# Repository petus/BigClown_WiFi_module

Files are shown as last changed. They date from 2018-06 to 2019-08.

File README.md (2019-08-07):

# BigClown WiFi module v1.0</br>
WiFi module for BigClown platform</br>
</br>
This WiFi module is developed for BigClown IoT platform. The WiFi module can be ESP07 or ESP12E (ESP8266 IC).</br>
</br>
How to use WiFi module for BigClown </br>
(czech language) - https://chiptron.cz/articles.php?article_id=182</br>
(english) - https://time4ee.com/articles.php?article_id=113</br>
</br>
The Wi-Fi module is supported by BigClown SDK</br>
https://github.com/bigclownlabs/bcf-sdk/blob/master/bcl/src/bc_esp8266.c</br>
Example with Wi-Fi module</br>
https://github.com/bigclownprojects/bcf-wifi-cryptoclock</br>

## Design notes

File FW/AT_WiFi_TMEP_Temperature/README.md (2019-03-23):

WiFi module with built-in temperature TMP112</br>
Temperature TMP112 sensor (I2C0) is built-in BigClown Core module</br>
and the sensor sends temperature to BigClown and then the BigClown </br>
sends the temperature to tmep.eu or tmep.cz by WiFi conection (WiFi module)</br>
CH_EN pin of ESP8266 module is connected GPIO_P8</br>
Reset pin of ESP8266 module is connected to GPIO_P6</br>
Created by Petus (2019)</br>
(czech)</br>
WiFi module https://chiptron.cz/articles.php?article_id=182</br>
(english)</br>
WiFi module https://time4ee.com/articles.php?article_id=113</br>
</br>
Fill in the</br>
static char host[]="HOSTNAME.tmep.eu";</br>
static char SSID[]="\"SSID\",";</br>
static char PASSWORD[]="\"PASSWORD\"";</br>
</br>
FW uses the TMP112 sensor on Core module

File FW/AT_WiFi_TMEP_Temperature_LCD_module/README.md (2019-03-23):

WiFi module with built-in TMP112 and LCD module</br>
Temperature TMP112 sensor (I2C0) is buil-in Core module</br>
and the sensor sends temperature to BigClown and then the BigClown </br>
sends the temperature to tmep.eu or tmep.cz by WiFi conection (WiFi module).</br>
The temperature is also shown on LCD</br>
CH_EN pin of ESP8266 module is connected GPIO_P8</br>
Reset pin of ESP8266 module is connected to GPIO_P6</br>
Created by Petus (2019)</br>
(czech)</br>
WiFi module https://chiptron.cz/articles.php?article_id=182</br>
(english)</br>
WiFi module https://time4ee.com/articles.php?article_id=113</br>
</br>
Fill in the</br>
static char host[]="HOSTNAME.tmep.eu";</br>
static char SSID[]=""SSID",";</br>
static char PASSWORD[]=""PASSWORD"";</br>
</br>
FW uses the TMP112 sensor on Core module</br>
</br>
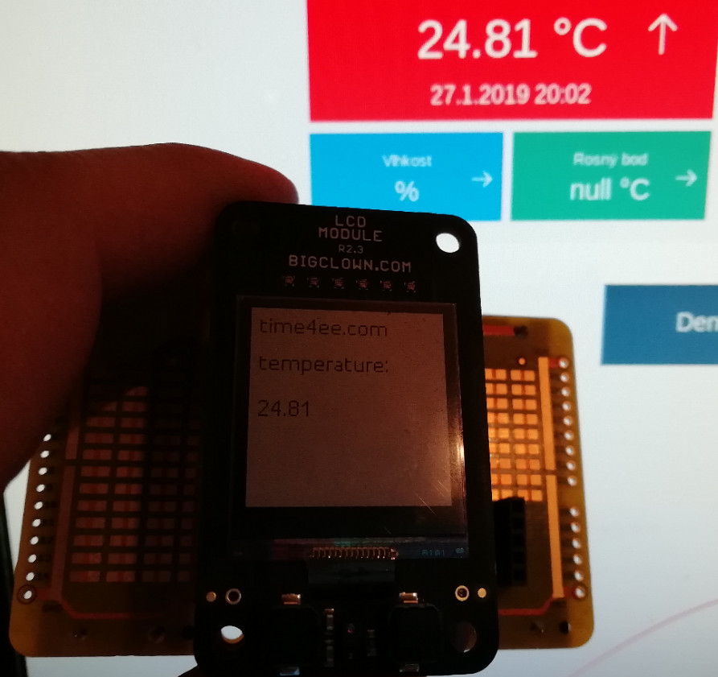
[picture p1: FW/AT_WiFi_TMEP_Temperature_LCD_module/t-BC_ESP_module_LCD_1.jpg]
BigClown and WiFi module


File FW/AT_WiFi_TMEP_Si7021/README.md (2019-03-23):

WiFi module and Sensor adapter - Si7021 example code (temperature)</br>
This example code demonstrates the settings and communication with temperature and humidity sensor Si7021 (0x40) and popular IoT platform called BigClown - https://www.bigclown.com/ .</br>
</br>
Created by Petus (2019)</br>
(czech) www.chiptron.cz - </br>
WiFi module https://chiptron.cz/articles.php?article_id=182</br>
Sensor adapter https://chiptron.cz/articles.php?article_id=194</br>
(english) www.time4ee.com - </br>
WiFi module https://time4ee.com/articles.php?article_id=113</br>
Sensor adapter https://time4ee.com/articles.php?article_id=119</br>

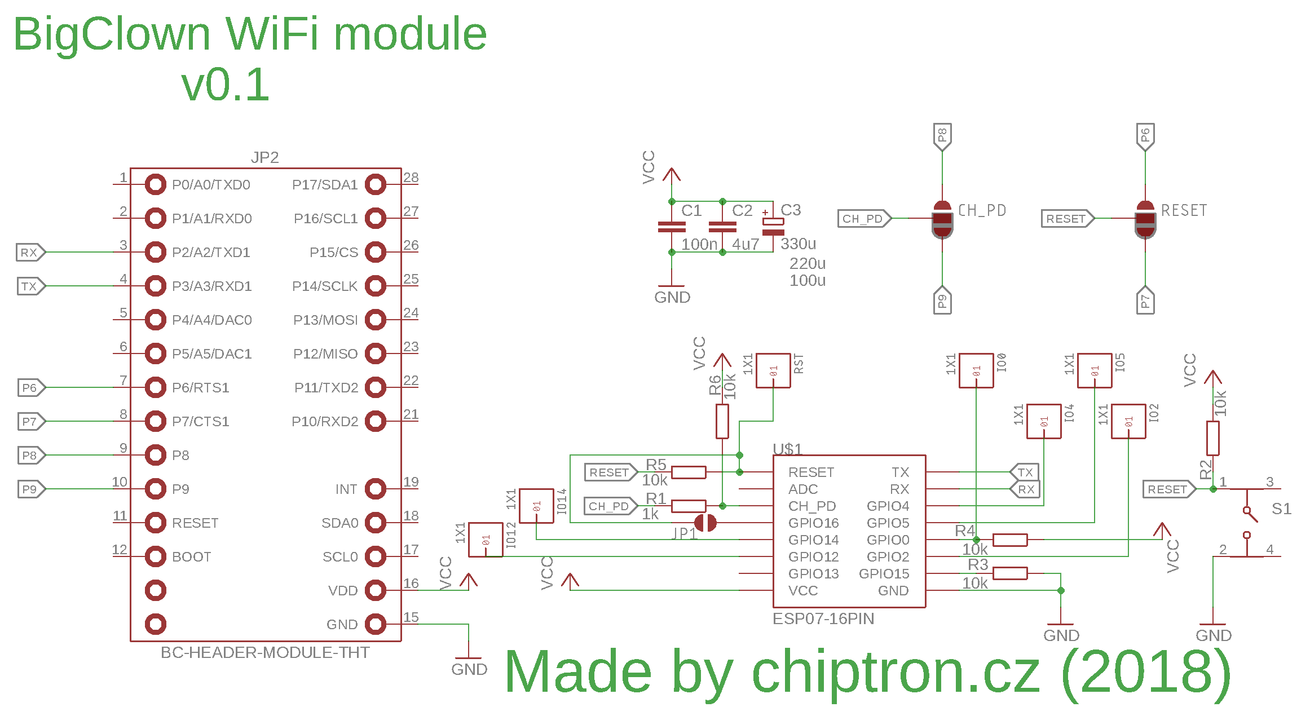
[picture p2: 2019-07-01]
BigClown_WiFi_module_sch.png

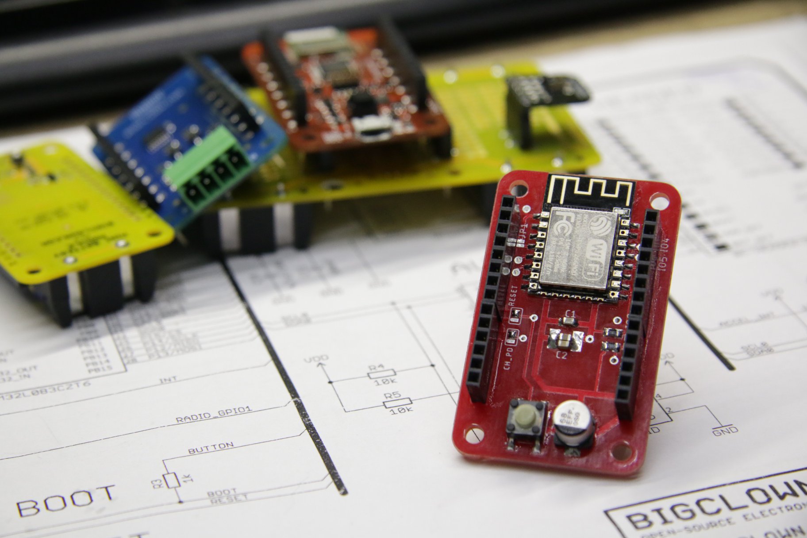
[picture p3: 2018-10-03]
Pictures/BigClown_WiFi_module_2_v1.0.jpg

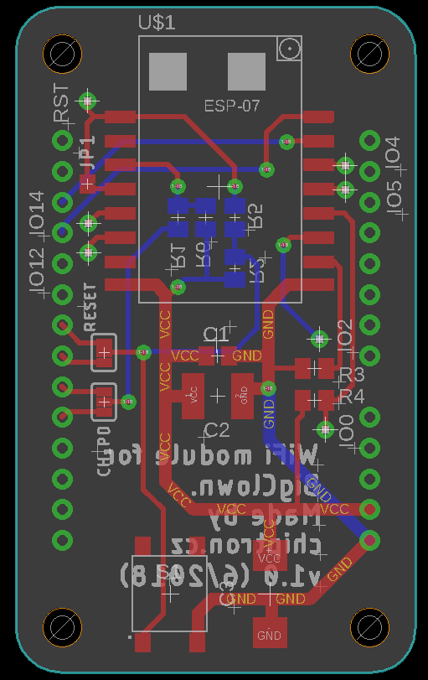
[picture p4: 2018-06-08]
BigClown_WiFi_module_brd.png

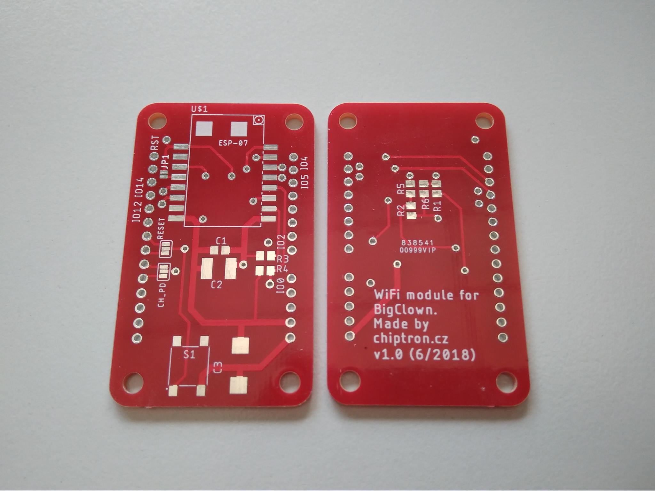
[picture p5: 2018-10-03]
Pictures/BigClown_WiFi_module_3_v1.0.jpg

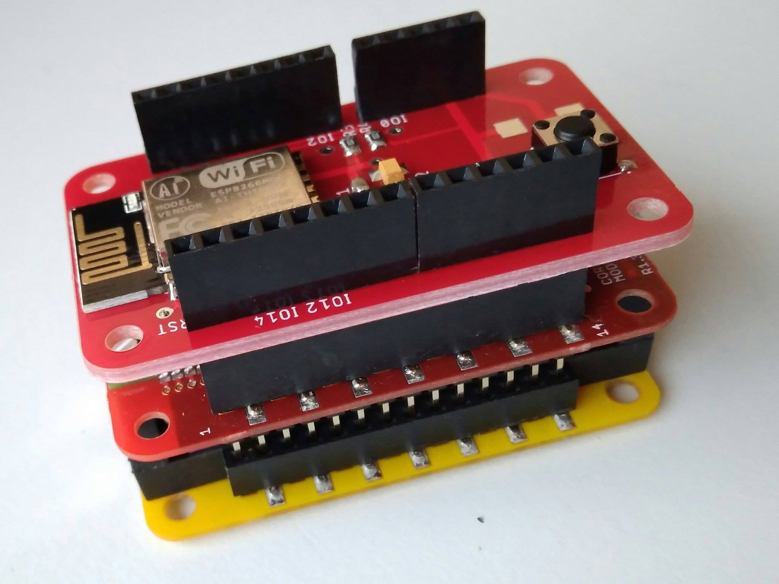
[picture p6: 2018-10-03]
Pictures/BigClown_WiFi_module_1_v1.0.jpg

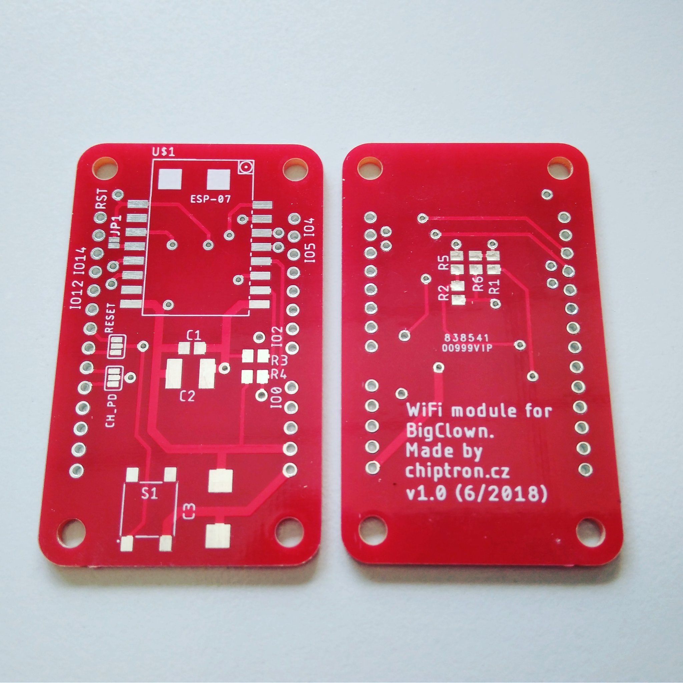
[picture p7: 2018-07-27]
BigClown_WiFi_module.jpeg

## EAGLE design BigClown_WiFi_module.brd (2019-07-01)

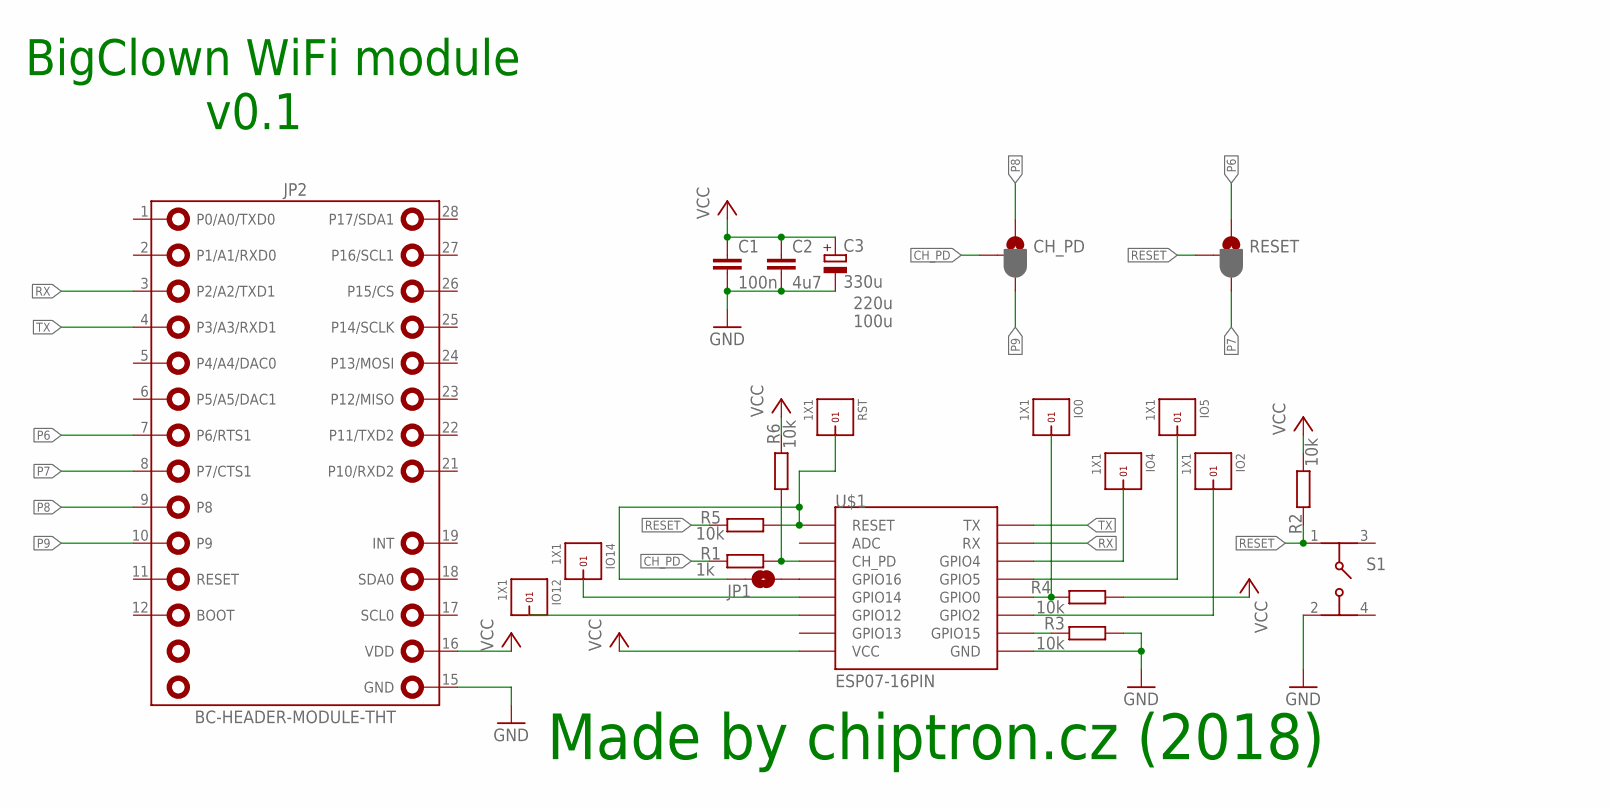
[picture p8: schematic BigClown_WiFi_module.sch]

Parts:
C1: 100n; C0805
C2: 4u7; C1812K
C3: 330u; D/7343-31R
CH_PD: JUMPER-SMT_3_1-NC_PASTE_SILK; SMT-JUMPER_3_1-NC_PASTE_SILK
IO0, IO2, IO4, IO5, IO12, IO14: 1X1
JP1: JUMPER-SMT_2_NO_NO-SILK; SMT-JUMPER_2_NO_NO-SILK
JP2: BC-HEADER-MODULE-THT
R1: 1k; M0805
R2, R3, R4, R5, R6: 10k; M0805
RESET: JUMPER-SMT_3_1-NC_PASTE_SILK; SMT-JUMPER_3_1-NC_PASTE_SILK
RST: 1X1
S1: 430152043826
U$1: ESP07-16PIN

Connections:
CH_PD: CH_PD.2, R1.1
GND: C1.2, C2.2, C3.-, JP2.15 (GND), R3.1, S1.2, U$1.GND
unnamed: R1.2, R6.1, U$1.CH_PD
unnamed: IO0.1, R4.2, U$1.GPIO0
unnamed: R3.2, U$1.GPIO15
unnamed: JP1.1, R5.2, RST.1, U$1.REST (RESET)
unnamed: JP1.2, U$1.GPIO16
unnamed: IO12.1, U$1.GPIO12
unnamed: IO14.1, U$1.GPIO14
unnamed: IO4.1, U$1.GPIO4
unnamed: IO5.1, U$1.GPIO5
unnamed: IO2.1, U$1.GPIO2
P6: JP2.7 (P6/RTS1), RESET.1
P7: JP2.8 (P7/CTS1), RESET.3
P8: CH_PD.1, JP2.9 (P8)
P9: CH_PD.3, JP2.10 (P9)
RESET: R2.1, R5.1, RESET.2, S1.1
RX: JP2.3 (P2/A2/TXD1), U$1.RX
TX: JP2.4 (P3/A3/RXD1), U$1.TX
VCC: C1.1, C2.1, C3.+, JP2.16 (VDD), R2.2, R4.1, R6.2, U$1.VCC

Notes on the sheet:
BigClown WiFi module
v0.1
Made by chiptron.cz (2018)
100u
220u

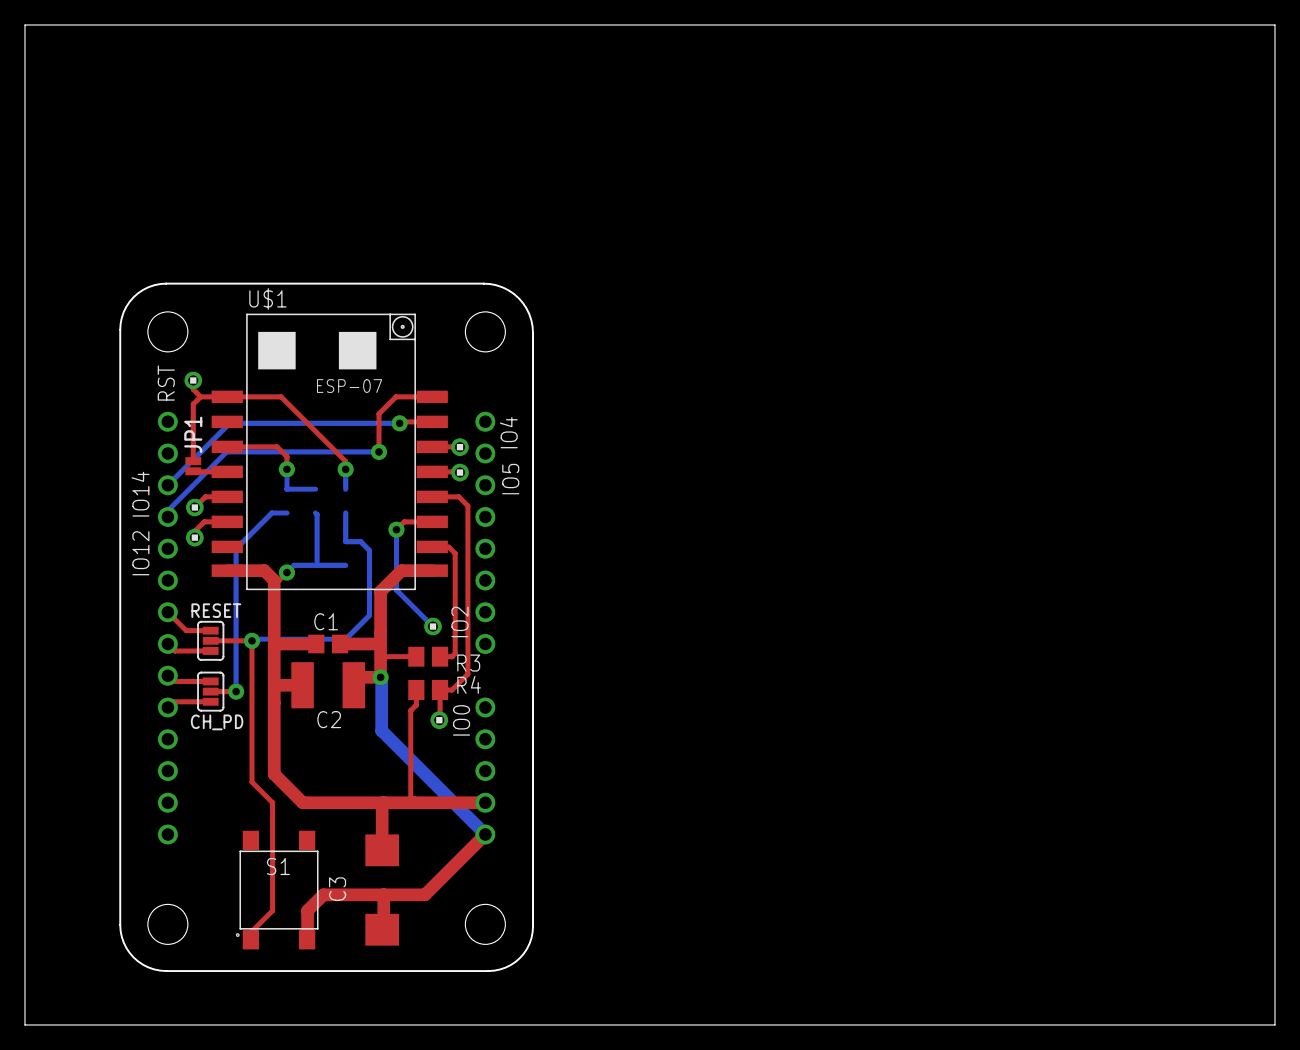
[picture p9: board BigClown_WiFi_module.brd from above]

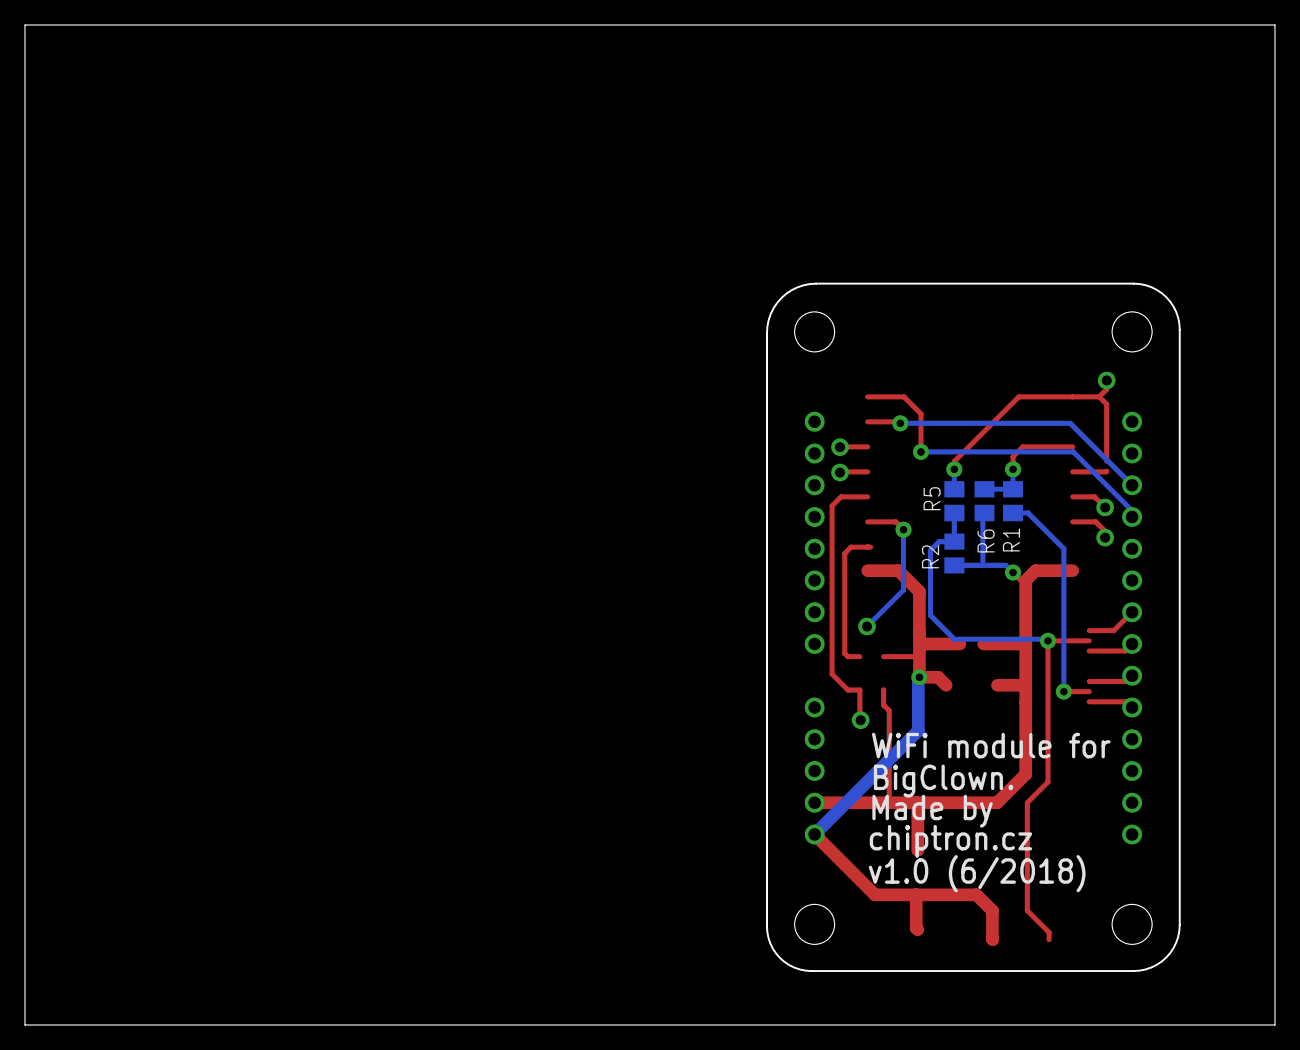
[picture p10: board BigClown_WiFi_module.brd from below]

Board: 2 copper layers, 100.0 x 80.0 mm, 22 parts (4 on the bottom side), 20 nets.

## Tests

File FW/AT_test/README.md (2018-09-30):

# AT test<br>
<br>
If you press the Boot button (label B):<br>
Core module sends AT\r\n<br>
ESP8266 responds OK<br>
</br>
Reset is connected to PC6</br>
CH_PD is connected to PC8</br>

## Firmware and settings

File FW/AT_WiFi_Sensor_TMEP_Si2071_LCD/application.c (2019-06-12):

#include <application.h>
#include <stdio.h>
#include <string.h>
#include "ESP_AT_command.h"

#define BLACK true

// LED instance
bc_led_t led;

// Temp
volatile float temperature = 0.0;
float voltage_value = 0;

static char host[]="HOSTNAME.tmep.cz";
static char url[]="GET /index.php?tempC=";
static char SSID[]="\"SSID\",";
static char PASSWORD[]="\"PASSWORD\"";

volatile char uart_tx[120]={0};
volatile char uart_rx[100]={0};

bc_i2c_transfer_t rx_transfer;
bc_i2c_transfer_t tx_transfer;
uint8_t tx_buffer[] = {0xE3}; // request for measurement

void turnOnESP(void)
{
    // CH_PD of ESP8266 
    bc_gpio_init(BC_GPIO_P8);
    bc_gpio_set_mode(BC_GPIO_P8, BC_GPIO_MODE_OUTPUT);
    bc_gpio_set_output(BC_GPIO_P8, 1);

    // RESET of ESP8266
    bc_gpio_init(BC_GPIO_P6);
    bc_gpio_set_mode(BC_GPIO_P6, BC_GPIO_MODE_OUTPUT);
    bc_gpio_set_output(BC_GPIO_P6, 1);

    bc_led_set_mode(&led, BC_LED_MODE_ON);
}

void turnOffESP(void)
{
    // CH_PD of ESP8266 
    bc_gpio_init(BC_GPIO_P8);
    bc_gpio_set_mode(BC_GPIO_P8, BC_GPIO_MODE_OUTPUT);
    bc_gpio_set_output(BC_GPIO_P8, 0);

    bc_led_set_mode(&led, BC_LED_MODE_OFF);
}

static void sendTemperature(void* param)
{    
    uint8_t rx_buffer[2] = {0x00};
    float temperature = 0x00;
    uint8_t str[50] = {0x00};

    // Toggle LED
    bc_led_set_mode(&led, BC_LED_MODE_TOGGLE);

    /********************************************
    *                                           *
    *               Temperature                 *
    *                                           *
    *********************************************/

    tx_transfer.device_address = 0x40;      // slave address
    tx_transfer.buffer = tx_buffer;         // 0xE3 - request for measurement
    tx_transfer.length = sizeof(tx_buffer);

    bc_i2c_write(BC_I2C_I2C0, &tx_transfer); // write

    rx_transfer.device_address = 0x40;      // slave address
    rx_transfer.buffer = rx_buffer;         // rx buffer - temperature
    rx_transfer.length = sizeof(rx_buffer);

    bc_i2c_read(BC_I2C_I2C0, &rx_transfer); // read

    temperature = ((rx_buffer[0] << 8) | rx_buffer[1]);    // sum MSB and LSB values

	temperature = ((175.72 * temperature)/65536) - 46.85;   // formula from datasheet

    char buffer[30]={0};
    char bufferBat[30]={0};
    sprintf(buffer, "%.2f", temperature);


    /********************************************
    *                                           *
    *                   LCD                     *
    *                                           *
    *********************************************/
    
    // clear LCD module
    bc_module_lcd_clear();

    // Init default font
    bc_module_lcd_set_font(&bc_font_ubuntu_33);

    // Temperature
    bc_module_lcd_draw_string(5, 30, &buffer[0], BLACK);

    // Init default font
    bc_module_lcd_set_font(&bc_font_ubuntu_15);

    //Temperature
    bc_module_lcd_draw_string(5, 10, "Teplota ", BLACK);
    bc_module_lcd_draw_string(5, 60, "°C", BLACK);


    // Battery
    sprintf(bufferBat, "%02.2f", voltage_value);
    bc_module_lcd_draw_string(3, 90, "Bat: ", BLACK);
    bc_module_lcd_draw_string(45, 90, &bufferBat[0], BLACK);
    bc_module_lcd_draw_string(85, 90, "V", BLACK);

    bc_module_lcd_draw_line(0, 108, 128, 108, BLACK);
    bc_module_lcd_draw_string(25, 110, "chiptron.cz", BLACK);

    bc_module_lcd_update();

    bc_uart_write(BC_UART_UART2, &buffer, strlen(buffer)); // send rx buffer through UART2

    turnOnESP();
    
    for(uint32_t i=0; i<0xFFFFF; i++)
    { ; }

    /* Send AT */
    uart_tx[0]='\0';
    strcat(uart_tx, uart_tx_AT);
    strcat(uart_tx, uart_tx_rn);
    uart_rx[0]='\0';
    bc_uart_write(BC_UART_UART1, uart_tx, strlen(uart_tx));
    bc_uart_read(BC_UART_UART1, uart_rx, sizeof(uart_rx), 1000);
    if(memcmp(uart_tx, uart_rx, sizeof(uart_tx)) != 0)
    {
        //turnOffESP();
    }
    else
    {
        
    }
    
    
    /* Send CIPSTART */
    uart_tx[0]='\0';
    strcat(uart_tx, uart_tx_CIPSTART);
    strcat(uart_tx, "\"TCP\",\"");
    strcat(uart_tx, host);
    strcat(uart_tx, "\",80");
    strcat(uart_tx, uart_tx_rn);
    uart_rx[0]='\0';
    bc_uart_write(BC_UART_UART1, uart_tx, strlen(uart_tx));
    bc_uart_read(BC_UART_UART1, uart_rx, sizeof(uart_rx), 5000);

    /* Send CIPSEND */
    uart_tx[0]='\0';
    strcat(uart_tx, uart_tx_CIPSEND);
    strcat(uart_tx, "62");
    strcat(uart_tx, uart_tx_rn);
    uart_rx[0]='\0';
    bc_uart_write(BC_UART_UART1, uart_tx, strlen(uart_tx));
    bc_uart_read(BC_UART_UART1, uart_rx, sizeof(uart_rx), 5000);

    /* Send HTTP GET request */
    uart_tx[0]='\0';
    strcpy(uart_tx, url);
    strcat(uart_tx, buffer);
    strcat(uart_tx, uart_tx_http_header);
    strcat(uart_tx, host);
    strcat(uart_tx, uart_tx_rnrnrn);
    
    uart_rx[0]='\0';
    bc_uart_write(BC_UART_UART1, uart_tx, strlen(uart_tx));
    bc_uart_read(BC_UART_UART1, uart_rx, sizeof(uart_rx), 2000);

    /* Send CIPCLOSE */
    uart_tx[0]='\0';
    strcat(uart_tx, uart_tx_CIPCLOSE);
    strcat(uart_tx, uart_tx_rn);
    uart_rx[0]='\0';
    bc_uart_write(BC_UART_UART1, uart_tx, strlen(uart_tx));
    bc_uart_read(BC_UART_UART1, uart_rx, sizeof(uart_rx), 1000);

    turnOffESP();

    // Execute the task
    bc_scheduler_plan_current_from_now(60000);
}


void application_init()
{
    // Initialize LED
    bc_led_init(&led, BC_GPIO_LED, false, false);
    bc_led_set_mode(&led, BC_LED_MODE_ON);

    // Initialize UART
    bc_uart_init(BC_UART_UART1, BC_UART_BAUDRATE_115200, BC_UART_SETTING_8N1);

    // Initialize UART
    bc_uart_init(BC_UART_UART2, BC_UART_BAUDRATE_115200, BC_UART_SETTING_8N1);

    // Initialize I2C0
    bc_i2c_init(BC_I2C_I2C0, BC_I2C_SPEED_100_KHZ);

    // Initialize LCD
    bc_module_lcd_init();

    // Initialize battery
    bc_module_battery_init();
    bc_module_battery_set_update_interval(10000);

    turnOnESP();
    
    for(uint32_t i=0; i<0xFFFFF; i++)
    { ; }

    /* Send CWMODE */
    uart_tx[0]='\0';
    strcat(uart_tx, uart_tx_CWMODE);
    strcat(uart_tx, uart_tx_rn);
    uart_rx[0]='\0';
    bc_uart_write(BC_UART_UART1, uart_tx, strlen(uart_tx));
    bc_uart_read(BC_UART_UART1, uart_rx, sizeof(uart_rx), 2000);

    /* Send CIPMUX */
    uart_tx[0]='\0';
    strcat(uart_tx, uart_tx_CIPMUX);
    strcat(uart_tx, uart_tx_rn);
    uart_rx[0]='\0';
    bc_uart_write(BC_UART_UART1, uart_tx, strlen(uart_tx));
    bc_uart_read(BC_UART_UART1, uart_rx, sizeof(uart_rx), 2000);

    /* Send CWJAP */
    uart_tx[0]='\0';
    strcat(uart_tx, uart_tx_CWJAP);
    strcat(uart_tx, SSID);
    strcat(uart_tx, PASSWORD);
    strcat(uart_tx, uart_tx_rn);
    uart_rx[0]='\0';
    bc_uart_write(BC_UART_UART1, uart_tx, strlen(uart_tx));
    bc_uart_read(BC_UART_UART1, uart_rx, sizeof(uart_rx), 5000);

    turnOffESP();

    // Timming
    bc_scheduler_register(sendTemperature, NULL, bc_tick_get() + 3000);
}

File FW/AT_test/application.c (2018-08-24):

#include <application.h>

// LED instance
bc_led_t led;

// Button instance
bc_button_t button;

void button_event_handler(bc_button_t *self, bc_button_event_t event, void *event_param)
{
    if (event == BC_BUTTON_EVENT_PRESS)
    {
        bc_led_set_mode(&led, BC_LED_MODE_TOGGLE);
        char uart_tx[] = "AT\r\n";
        bc_uart_write(BC_UART_UART1, uart_tx, strlen(uart_tx));
    }
}

void application_init(void)
{
    // Initialize LED
    bc_led_init(&led, BC_GPIO_LED, false, false);
    bc_led_set_mode(&led, BC_LED_MODE_ON);

    // RESET of ESP8266
    bc_gpio_init(BC_GPIO_P6);
    bc_gpio_set_mode(BC_GPIO_P6, BC_GPIO_MODE_OUTPUT);
    bc_gpio_set_output(BC_GPIO_P6, 1);

    //CH_PD of ESP8266 
    bc_gpio_init(BC_GPIO_P8);
    bc_gpio_set_mode(BC_GPIO_P8, BC_GPIO_MODE_OUTPUT);
    bc_gpio_set_output(BC_GPIO_P8, 1);

    // Initialize button
    bc_button_init(&button, BC_GPIO_BUTTON, BC_GPIO_PULL_DOWN, false);
    bc_button_set_event_handler(&button, button_event_handler, NULL);

    // Initialize UART
    bc_uart_init(BC_UART_UART1, BC_UART_BAUDRATE_115200, BC_UART_SETTING_8N1);
}

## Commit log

2018-06-06 Add files via upload
    The initial commit of WiFi module for BigClown
    [BigClown_WiFi_module.brd, BigClown_WiFi_module.sch]
2018-06-06 Add files via upload
    new version of design
    [BigClown_WiFi_module.brd]
2018-06-07 v1.0
    added pins for gpio
    added labels
    [BigClown_WiFi_module.brd, BigClown_WiFi_module.sch]
2018-09-29 first commit
    Temperature from TMP112 sensor is sent to tmep.eu with WiFi module

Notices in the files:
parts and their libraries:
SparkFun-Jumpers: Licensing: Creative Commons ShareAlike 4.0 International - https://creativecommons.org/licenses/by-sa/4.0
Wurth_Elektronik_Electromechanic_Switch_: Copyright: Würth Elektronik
